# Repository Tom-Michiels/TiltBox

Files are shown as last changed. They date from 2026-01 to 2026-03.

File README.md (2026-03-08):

# TiltBox

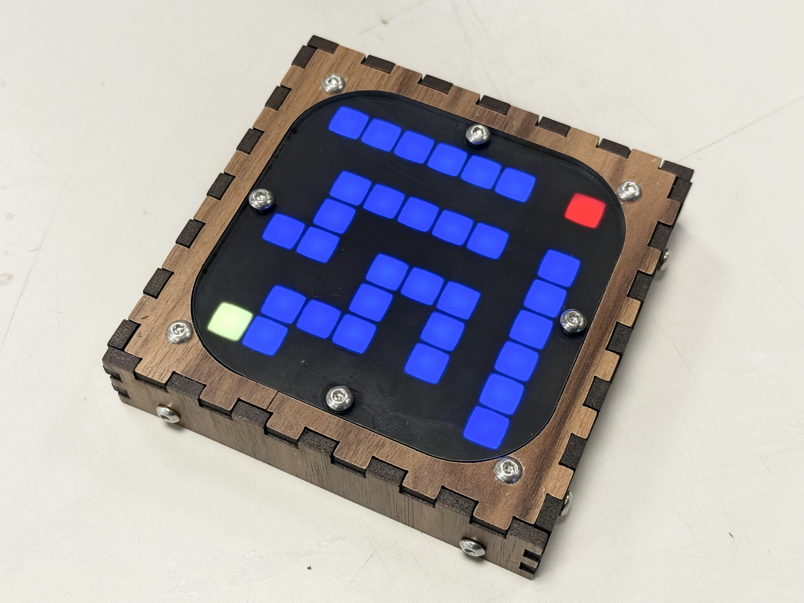
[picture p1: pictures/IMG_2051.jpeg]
TiltBox


A handheld retro game console with tilt controls, featuring 9 games on an 8x8 LED matrix. Designed at [Maakleerplek](https://maakleerplek.be).

## Bill of Materials

| Component | Quantity | Description | Link |
|---|---|---|---|
| ESP32-C3 | 1 | Microcontroller (any ESP32-C3 dev board) | [Amazon](https://www.amazon.de/diymore-ESP32-C3-Development-Supports-Bluetooth/dp/B0DS23ML1L/ref=sr_1_1_sspa?th=1) |
| WS2812 8x8 LED Matrix | 1 | 64 RGB LEDs in 8x8 grid | [Amazon](https://www.amazon.de/CJMCU-8x8-Development-Compatible-Arduino-Raspberry/dp/B0DDPWTH83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) |
| ADXL345 | 1 | 3-axis accelerometer module (I2C) | [Amazon](https://www.amazon.de/APKLVSR-ADXL345-Digital-Accelerating-Transmission/dp/B0CRVL4S54/ref=sr_1_2_sspa) |
| USB Charger Board | 1 | LiPo charging module with protection | [Amazon](https://www.amazon.de/-/en/dp/B09C34TK4F?th=1) |
| LiPo Battery | 1 | 3.7V lithium polymer battery | [Amazon](https://www.amazon.de/-/en/Seamuing-Lithium-Protective-Insulation-Development/dp/B087LTZW61/ref=sr_1_12) |
| Threaded Inserts | 4 | M3x5x7 heat-set inserts for enclosure | [Amazon](https://www.amazon.de/Threaded-RX-M3x5-7-Lead-Free-Bushings-Insertion/dp/B08BCRZZS3/ref=sr_1_1_sspa) |
| M3 Screws | 4 | M3x6mm hex socket button head | [Amazon](https://www.amazon.de/dp/B07ZPTX8B2?ref=ppx_yo2ov_dt_b_fed_asin_title) |
| M3 Screws | 4 | M3x12mm hex socket button head | [Amazon](https://www.amazon.de/dp/B07ZPT7Y9R?ref=ppx_yo2ov_dt_b_fed_asin_title&th=1) |
| Walnut Wood | 1 | 3.2mm x 115x368mm sheet | [Gravierbedarf](https://www.gravierbedarf.de/epages/63201300.sf/en_GB/?ObjectPath=/Shops/63201300/Products/NUSS) |
| Black PLA | 1 | 3D printer filament for enclosure | |
| Jumper wires | 7 | For connections | |

## Wiring

### WS2812 LED Matrix

| WS2812 Pin | ESP32-C3 Pin |
|---|---|
| VCC | 5V |
| GND | GND |
| DIN | GPIO 10 |

### ADXL345 Accelerometer (I2C)

| ADXL345 Pin | ESP32-C3 Pin |
|---|---|
| VCC | 3.3V |
| GND | GND |
| SDA | GPIO 8 |
| SCL | GPIO 9 |

## Build Instructions

### 1. 3D Printing

Print the enclosure parts in black PLA:

- [tilt_box.stl](hardware/tilt_box.stl) - Main enclosure body
- [tilt box grid.stl](hardware/tilt%20box%20grid.stl) - Grid overlay

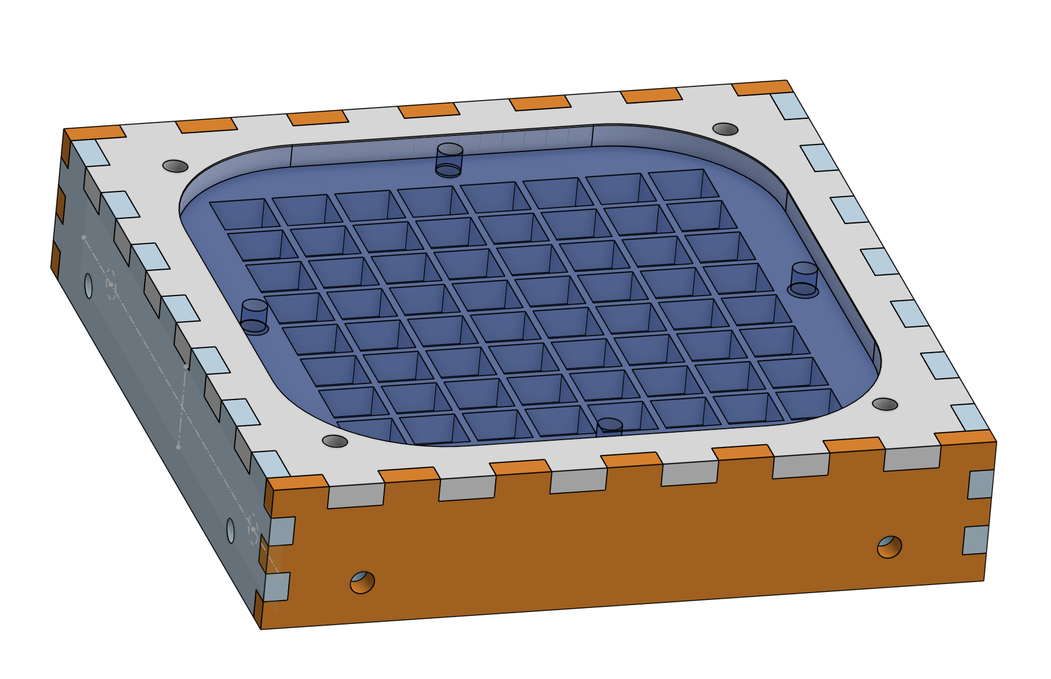
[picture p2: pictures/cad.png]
CAD Model


[Open in Onshape](https://cad.onshape.com/documents/1ea29db64e579952e6381490/w/44e133dfefb2de18973d13df/e/b5270f9dee790fa11f86224a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)

### 2. Laser Cutting

Cut the following from the [wood and plexi.dxf](hardware/wood%20and%20plexi.dxf) file:

- **Walnut wood** (3.2mm thickness): Front frame
- **Clear acrylic/plexi**: Screen cover

### 3. Soldering

Solder the components according to the wiring diagram:

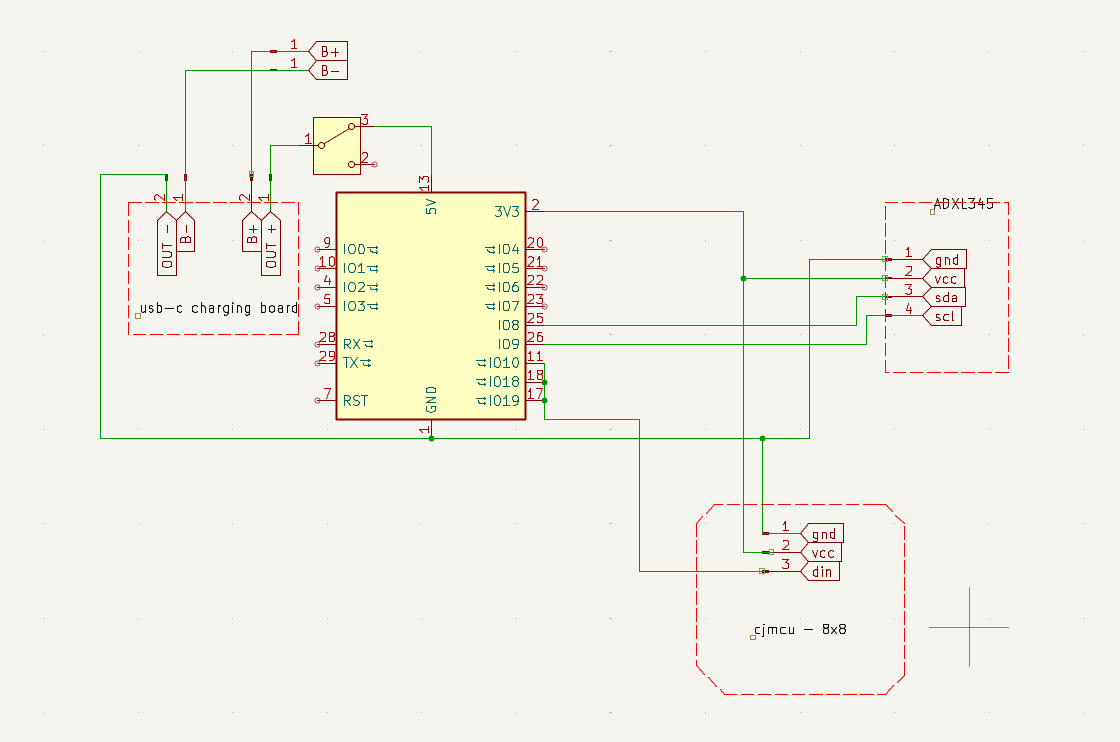
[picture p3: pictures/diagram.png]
Wiring Diagram


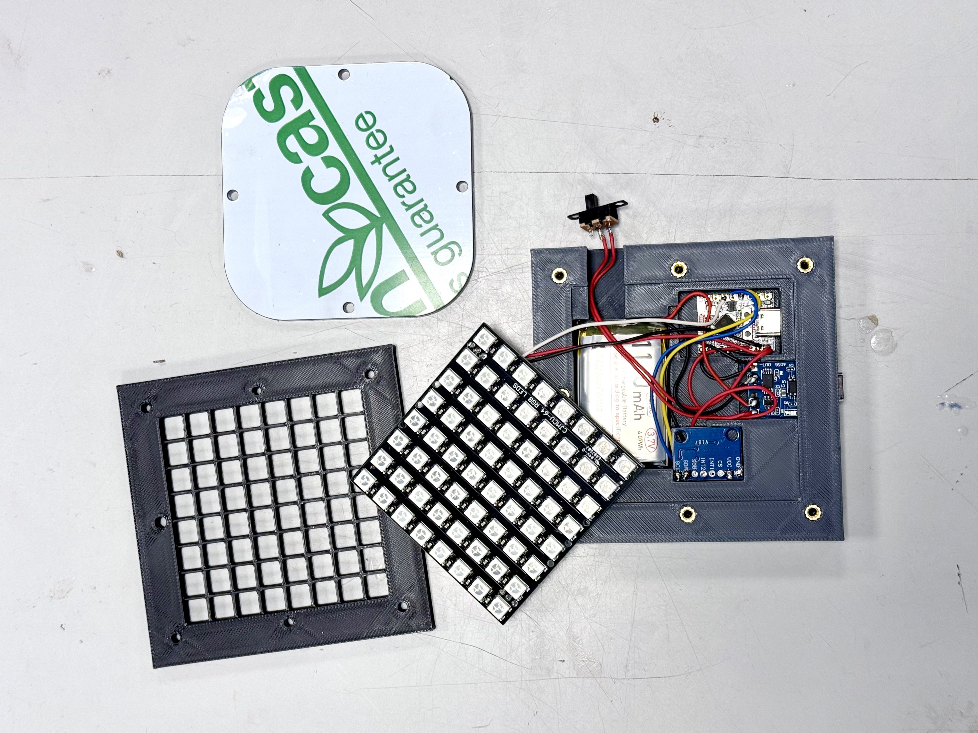
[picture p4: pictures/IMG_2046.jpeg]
Assembly


### 4. Screen Assembly

The LED matrix needs a diffuser layer to blend the individual LEDs into a smooth display:

- **Diffuser**: Use a white plastic bag or similar translucent material between the LED matrix and the plexi cover
- **Optional darkening**: Adding a dark PVC film (e.g. available at Lukas Creative) provides additional darkness to the screen, improving contrast

### 5. Final Assembly

1. Insert the M3x5x7 threaded inserts into the 3D printed enclosure using a soldering iron
2. Mount all electronics inside the enclosure
3. Stack the layers: LED matrix -> diffuser -> (optional dark film) -> plexi -> walnut frame
4. Secure with M3x6mm screws (front) and M3x12mm screws (back)

## Games

Switch between games by flipping the board upside down.

### 1. Maze
Navigate a ball through a randomly generated maze. Tilt to move the yellow ball to the red goal. A rainbow animation plays when you win.

### 2. Ball Trail
A simple ball that leaves a fading trail as it moves. Tilt to control direction.

### 3. Glow Ball
A glowing ball with a smooth gradient effect that follows your tilt movements.

### 4. Snake
Classic snake game. Tilt to change direction and eat the red food to grow. Don't hit yourself!

### 5. Breakout
Break the colored bricks at the top with a bouncing ball. Tilt left/right to move the paddle.

### 6. Dodge
Avoid falling obstacles. Tilt left/right to move your player at the bottom. Score increases as obstacles pass.

### 7. Scroll Text
Displays scrolling text: "maakleerplek"

### 8. Animation
Cycles through animated patterns:
- Spiral rainbow
- Wave
- Rainbow gradient

### 9. Tetris
Classic falling block game. Tilt left/right to move pieces, tilt forward to rotate, tilt backward for fast drop.

## Building and Flashing

Requires ESP-IDF v4.3+.

```bash
# Source ESP-IDF environment
source ~/esp/esp-idf/export.sh

# Build
idf.py build

# Flash
idf.py flash

# Monitor serial output
idf.py monitor
```

## Controls

- **Tilt**: Move/control in all games
- **Flip board**: Switch to next game
- **Keep level during startup**: Calibrates the accelerometer

## Display Format

The WS2812 LEDs use GRB color format. Pixels are addressed row by row, 0-63.

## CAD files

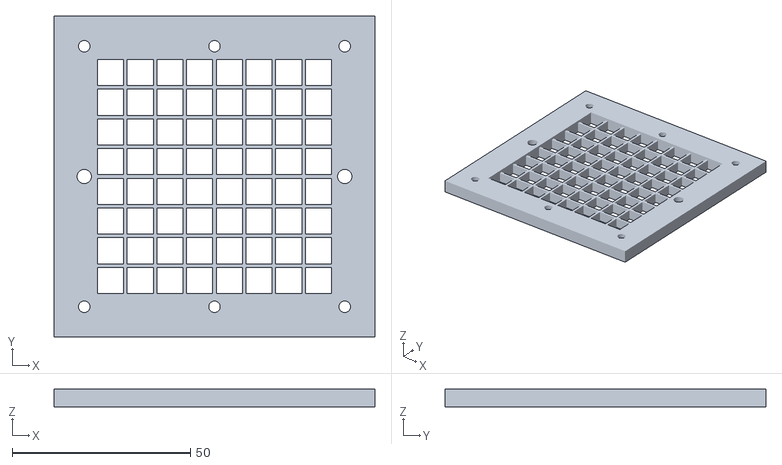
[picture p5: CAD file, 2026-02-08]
hardware/tilt box grid.stl
90.0 x 90.0 x 5.00

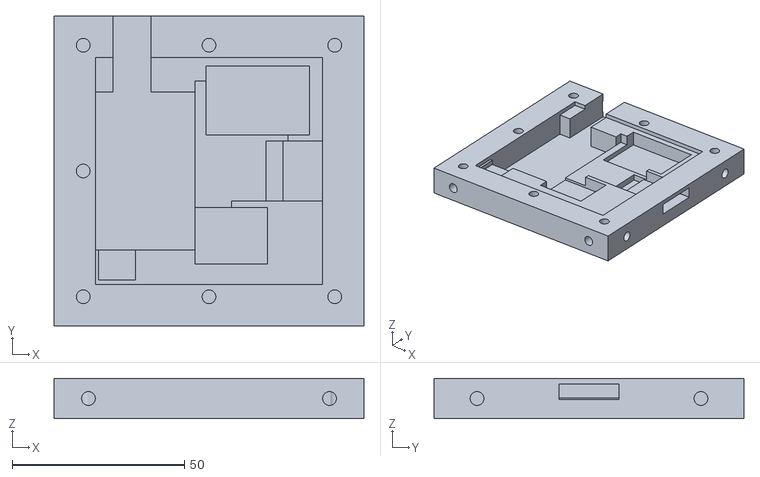
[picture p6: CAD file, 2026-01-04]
hardware/tilt_box.stl
90.0 x 90.0 x 11.7

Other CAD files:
hardware/wood and plexi.dxf

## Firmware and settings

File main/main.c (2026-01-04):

#include <stdio.h>
#include <string.h>
#include <math.h>
#include <stdlib.h>
#include "freertos/FreeRTOS.h"
#include "freertos/task.h"
#include "driver/rmt.h"
#include "driver/i2c.h"
#include "esp_system.h"

// I2C config
#define I2C_PORT        I2C_NUM_0
#define I2C_SDA         GPIO_NUM_8
#define I2C_SCL         GPIO_NUM_9
#define I2C_FREQ_HZ     100000

// ADXL345 registers
#define ADXL345_ADDR        0x53
#define ADXL345_DEVID       0x00
#define ADXL345_BW_RATE     0x2C
#define ADXL345_POWER_CTL   0x2D
#define ADXL345_DATA_FORMAT 0x31
#define ADXL345_DATAX0      0x32

// WS2812 config
#define WS2812_PIN      GPIO_NUM_10
#define RMT_CHANNEL     RMT_CHANNEL_0
#define LED_COUNT       64

// WS2812 timing (in RMT ticks at 10MHz = 100ns per tick)
#define T0H  4
#define T0L  8
#define T1H  8
#define T1L  4

// Colors (GRB format)
#define BLACK  0x00, 0x00, 0x00
#define WHITE  0xFF, 0xFF, 0xFF
#define RED    0x00, 0x40, 0x00
#define GREEN  0x40, 0x00, 0x00
#define BLUE   0x00, 0x00, 0x40
#define YELLOW 0x40, 0x40, 0x00

// Tilt threshold
#define TILT_THRESHOLD 25

// Flip detection
#define Z_POSITIVE_THRESHOLD  50
#define Z_NEGATIVE_THRESHOLD -50
#define FLIP_DEBOUNCE_COUNT   5

// Game types
typedef enum {
    GAME_MAZE,
    GAME_BALL_TRAIL,
    GAME_GLOW_BALL,
    GAME_SNAKE,
    GAME_BREAKOUT,
    GAME_DODGE,
    GAME_SCROLL_TEXT,
    GAME_ANIMATION,
    GAME_TETRIS,
    GAME_COUNT
} game_t;

typedef struct {
    void (*init)(void);
    void (*update)(int16_t dx, int16_t dy, int16_t z);
    void (*draw)(void);
} game_interface_t;

typedef struct {
    int8_t x, y;
} position_t;

// Display buffers
static uint8_t led_data[LED_COUNT * 3];
static rmt_item32_t rmt_items[LED_COUNT * 24];

// Calibration values
static int16_t cal_x = 0, cal_y = 0;

// Current game state
static game_t current_game = GAME_MAZE;

// Flip detection state
static bool z_positive = true;
static int flip_debounce_counter = 0;

// Animation frame counter (shared)
static uint32_t anim_frame = 0;

// ============ Ball with Trail Game ============
#define TRAIL_LENGTH 8
static position_t trail_buffer[TRAIL_LENGTH];
static int trail_head = 0;
static int ball_x = 3;
static int ball_y = 3;

// ============ Glow Ball Game ============
static float glow_ball_x = 3.5f;
static float glow_ball_y = 3.5f;

// ============ Snake Game ============
#define MAX_SNAKE_LENGTH 64
#define SNAKE_MOVE_INTERVAL 6
static position_t snake_body[MAX_SNAKE_LENGTH];
static int snake_length = 3;
static int8_t snake_dir_x = 1, snake_dir_y = 0;
static position_t food_pos;
static bool snake_alive = true;
static int snake_move_counter = 0;

// ============ Maze Game ============
static uint8_t maze[8];
static position_t maze_ball;
static position_t maze_goal;
static bool maze_won = false;
static int maze_win_counter = 0;

// ============ Dodge Game ============
static int dodge_player_x = 3;
static int16_t dodge_last_dx = 0;  // For hysteresis
static float dodge_obstacles[8];  // Y position of obstacle in each column (-1 = none)
static int dodge_score = 0;
static bool dodge_alive = true;
static int dodge_anim_counter = 0;
static int dodge_speed_counter = 0;
static float dodge_fall_speed = 0.15f;

// ============ Scroll Text Game ============
static float scroll_pos = 8.0f;  // Start off-screen to the right

// ============ Breakout Game ============
static int breakout_paddle_x = 3;        // Paddle center position (0-7)
static int16_t breakout_last_dx = 0;     // For hysteresis
static float breakout_ball_x = 3.5f;     // Ball position (float for smooth movement)
static float breakout_ball_y = 5.5f;
static float breakout_ball_vx = 0.3f;    // Ball velocity
static float breakout_ball_vy = -0.3f;
static uint8_t breakout_bricks[3];       // 3 rows of 8 bricks (bitmask)
static int breakout_bricks_left = 24;
static bool breakout_won = false;
static bool breakout_lost = false;
static int breakout_anim_counter = 0;

// ============ Animation Mode ============
typedef enum {
    ANIM_SPIRAL,
    ANIM_WAVE,
    ANIM_RAINBOW,
    ANIM_COUNT
} animation_t;
static animation_t current_anim = ANIM_SPIRAL;
static uint32_t anim_cycle_counter = 0;
#define ANIM_CYCLE_FRAMES 200

// ============ Tetris Game ============
#define TETRIS_DROP_INTERVAL 12
#define TETRIS_MOVE_DELAY 3
static uint8_t tetris_board[8];  // 8 rows, each byte is 8 columns (bitmask)
static int8_t tetris_piece_x, tetris_piece_y;  // Current piece position
static int8_t tetris_piece_type;  // 0-6 for I,O,T,S,Z,L,J
static int8_t tetris_piece_rot;   // 0-3 rotation
static int tetris_drop_counter;
static int tetris_move_counter;
static bool tetris_game_over;
static int tetris_anim_counter;
static int16_t tetris_last_dx;

// Tetromino shapes: 4 rotations each, stored as 4x4 bitmask (16 bits)
// Encoded as which cells are filled relative to piece origin
static const uint16_t tetris_pieces[7][4] = {
    // I piece
    {0x0F00, 0x2222, 0x00F0, 0x4444},
    // O piece
    {0x6600, 0x6600, 0x6600, 0x6600},
    // T piece
    {0x0E40, 0x4C40, 0x4E00, 0x4640},
    // S piece
    {0x06C0, 0x8C40, 0x6C00, 0x4620},
    // Z piece
    {0x0C60, 0x4C80, 0xC600, 0x2640},
    // L piece
    {0x0E80, 0xC440, 0x2E00, 0x44C0},
    // J piece
    {0x0E20, 0x44C0, 0x8E00, 0xC440},
};

// Piece colors (GRB format)
static const uint8_t tetris_colors[7][3] = {
    {0x40, 0x00, 0x40},  // I - cyan
    {0x40, 0x40, 0x00},  // O - yellow
    {0x20, 0x00, 0x40},  // T - purple
    {0x40, 0x00, 0x00},  // S - green
    {0x00, 0x40, 0x00},  // Z - red
    {0x20, 0x40, 0x00},  // L - orange
    {0x00, 0x00, 0x40},  // J - blue
};

// Forward declarations
static void ball_trail_init(void);
static void ball_trail_update(int16_t dx, int16_t dy, int16_t z);
static void ball_trail_draw(void);

static void glow_ball_init(void);
static void glow_ball_update(int16_t dx, int16_t dy, int16_t z);
static void glow_ball_draw(void);

static void snake_init(void);
static void snake_update(int16_t dx, int16_t dy, int16_t z);
static void snake_draw(void);

static void maze_init(void);
static void maze_update(int16_t dx, int16_t dy, int16_t z);
static void maze_draw(void);

static void breakout_init(void);
static void breakout_update(int16_t dx, int16_t dy, int16_t z);
static void breakout_draw(void);

static void dodge_init(void);
static void dodge_update(int16_t dx, int16_t dy, int16_t z);
static void dodge_draw(void);

static void scroll_text_init(void);
static void scroll_text_update(int16_t dx, int16_t dy, int16_t z);
static void scroll_text_draw(void);

static void animation_init(void);
static void animation_update(int16_t dx, int16_t dy, int16_t z);
static void animation_draw(void);

static void tetris_init(void);
static void tetris_update(int16_t dx, int16_t dy, int16_t z);
static void tetris_draw(void);

// Game dispatch table
static const game_interface_t game_table[GAME_COUNT] = {
    { maze_init, maze_update, maze_draw },
    { ball_trail_init, ball_trail_update, ball_trail_draw },
    { glow_ball_init, glow_ball_update, glow_ball_draw },
    { snake_init, snake_update, snake_draw },
    { breakout_init, breakout_update, breakout_draw },
    { dodge_init, dodge_update, dodge_draw },
    { scroll_text_init, scroll_text_update, scroll_text_draw },
    { animation_init, animation_update, animation_draw },
    { tetris_init, tetris_update, tetris_draw },
};

// ============ Display Functions ============

static int get_led_index(int row, int col)
{
    return row * 8 + col;
}

static void set_pixel_at(int row, int col, uint8_t g, uint8_t r, uint8_t b)
{
    if (row >= 0 && row < 8 && col >= 0 && col < 8) {
        int index = get_led_index(row, col);
        led_data[index * 3 + 0] = g;
        led_data[index * 3 + 1] = r;
        led_data[index * 3 + 2] = b;
    }
}

static void clear_display(void)
{
    memset(led_data, 0, sizeof(led_data));
}

static void ws2812_init(void)
{
    rmt_config_t config = {
        .rmt_mode = RMT_MODE_TX,
        .channel = RMT_CHANNEL,
        .gpio_num = WS2812_PIN,
        .clk_div = 8,
        .mem_block_num = 4,
        .tx_config = {
            .loop_en = false,
            .carrier_en = false,
            .idle_output_en = true,
            .idle_level = RMT_IDLE_LEVEL_LOW,
        }
    };
    rmt_config(&config);
    rmt_driver_install(RMT_CHANNEL, 0, 0);
}

static void ws2812_send(void)
{
    int item_idx = 0;
    for (int i = 0; i < LED_COUNT * 3; i++) {
        uint8_t byte = led_data[i];
        for (int bit = 7; bit >= 0; bit--) {
            if (byte & (1 << bit)) {
                rmt_items[item_idx].duration0 = T1H;
                rmt_items[item_idx].level0 = 1;
                rmt_items[item_idx].duration1 = T1L;
                rmt_items[item_idx].level1 = 0;
            } else {
                rmt_items[item_idx].duration0 = T0H;
                rmt_items[item_idx].level0 = 1;
                rmt_items[item_idx].duration1 = T0L;
                rmt_items[item_idx].level1 = 0;
            }
            item_idx++;
        }
    }
    rmt_write_items(RMT_CHANNEL, rmt_items, item_idx, true);
}

// ============ I2C / Accelerometer Functions ============

static void i2c_init(void)
{
    i2c_config_t conf = {
        .mode = I2C_MODE_MASTER,
        .sda_io_num = I2C_SDA,
        .scl_io_num = I2C_SCL,
        .sda_pullup_en = GPIO_PULLUP_ENABLE,
        .scl_pullup_en = GPIO_PULLUP_ENABLE,
        .master.clk_speed = I2C_FREQ_HZ,
    };
    i2c_param_config(I2C_PORT, &conf);
    i2c_driver_install(I2C_PORT, conf.mode, 0, 0, 0);
}

static esp_err_t adxl345_write_reg(uint8_t reg, uint8_t value)
{
    i2c_cmd_handle_t cmd = i2c_cmd_link_create();
    i2c_master_start(cmd);
    i2c_master_write_byte(cmd, (ADXL345_ADDR << 1) | I2C_MASTER_WRITE, true);
    i2c_master_write_byte(cmd, reg, true);
    i2c_master_write_byte(cmd, value, true);
    i2c_master_stop(cmd);
    esp_err_t ret = i2c_master_cmd_begin(I2C_PORT, cmd, pdMS_TO_TICKS(100));
    i2c_cmd_link_delete(cmd);
    return ret;
}

static esp_err_t adxl345_read_reg(uint8_t reg, uint8_t *data, size_t len)
{
    i2c_cmd_handle_t cmd = i2c_cmd_link_create();
    i2c_master_start(cmd);
    i2c_master_write_byte(cmd, (ADXL345_ADDR << 1) | I2C_MASTER_WRITE, true);
    i2c_master_write_byte(cmd, reg, true);
    i2c_master_start(cmd);
    i2c_master_write_byte(cmd, (ADXL345_ADDR << 1) | I2C_MASTER_READ, true);
    if (len > 1) {
        i2c_master_read(cmd, data, len - 1, I2C_MASTER_ACK);
    }
    i2c_master_read_byte(cmd, data + len - 1, I2C_MASTER_NACK);
    i2c_master_stop(cmd);
    esp_err_t ret = i2c_master_cmd_begin(I2C_PORT, cmd, pdMS_TO_TICKS(100));
    i2c_cmd_link_delete(cmd);
    return ret;
}

static esp_err_t adxl345_init(void)
{
    uint8_t devid;
    esp_err_t ret = adxl345_read_reg(ADXL345_DEVID, &devid, 1);
    if (ret != ESP_OK) return ret;
    if (devid != 0xE5) {
        printf("ADXL345 wrong ID: 0x%02X (expected 0xE5)\n", devid);
        return ESP_ERR_NOT_FOUND;
    }

    ret = adxl345_write_reg(ADXL345_BW_RATE, 0x0A);
    if (ret != ESP_OK) return ret;

    ret = adxl345_write_reg(ADXL345_DATA_FORMAT, 0x09);
    if (ret != ESP_OK) return ret;

    ret = adxl345_write_reg(ADXL345_POWER_CTL, 0x08);
    if (ret != ESP_OK) return ret;

    vTaskDelay(pdMS_TO_TICKS(10));
    return ESP_OK;
}

static esp_err_t adxl345_read(int16_t *x, int16_t *y, int16_t *z)
{
    uint8_t data[6];
    esp_err_t ret = adxl345_read_reg(ADXL345_DATAX0, data, 6);
    if (ret != ESP_OK) return ret;

    *x = (int16_t)((data[1] << 8) | data[0]);
    *y = (int16_t)((data[3] << 8) | data[2]);
    *z = (int16_t)((data[5] << 8) | data[4]);
    return ESP_OK;
}

static void calibrate_accel(void)
{
    int32_t sum_x = 0, sum_y = 0;
    int samples = 20;

    printf("Calibrating accelerometer - keep board level...\n");

    for (int i = 0; i < samples; i++) {
        int16_t x, y, z;
        if (adxl345_read(&x, &y, &z) == ESP_OK) {
            sum_x += x;
            sum_y += y;
        }
        vTaskDelay(pdMS_TO_TICKS(50));
    }

    cal_x = sum_x / samples;
    cal_y = sum_y / samples;

    printf("Calibration done: x=%d, y=%d\n", cal_x, cal_y);
}

// ============ Flip Detection ============

static bool check_game_switch(int16_t z)
{
    bool currently_positive = z > Z_POSITIVE_THRESHOLD;
    bool currently_negative = z < Z_NEGATIVE_THRESHOLD;

    if (z_positive && currently_negative) {
        flip_debounce_counter++;
        if (flip_debounce_counter >= FLIP_DEBOUNCE_COUNT) {
            z_positive = false;
            flip_debounce_counter = 0;
            return true;
        }
    } else if (!z_positive && currently_positive) {
        flip_debounce_counter++;
        if (flip_debounce_counter >= FLIP_DEBOUNCE_COUNT) {
            z_positive = true;
            flip_debounce_counter = 0;
        }
    } else {
        flip_debounce_counter = 0;
    }

    return false;
}

// ============ Utility Functions ============

static void hsv_to_rgb(uint8_t h, uint8_t s, uint8_t v, uint8_t *g, uint8_t *r, uint8_t *b)
{
    uint8_t region = h / 43;
    uint8_t remainder = (h - (region * 43)) * 6;
    uint8_t p = (v * (255 - s)) >> 8;
    uint8_t q = (v * (255 - ((s * remainder) >> 8))) >> 8;
    uint8_t t = (v * (255 - ((s * (255 - remainder)) >> 8))) >> 8;

    switch (region) {
        case 0:  *r = v; *g = t; *b = p; break;
        case 1:  *r = q; *g = v; *b = p; break;
        case 2:  *r = p; *g = v; *b = t; break;
        case 3:  *r = p; *g = q; *b = v; break;
        case 4:  *r = t; *g = p; *b = v; break;
        default: *r = v; *g = p; *b = q; break;
    }
}

// ============ Ball with Trail Game ============

static void ball_trail_init(void)
{
    ball_x = 3;
    ball_y = 3;
    trail_head = 0;
    for (int i = 0; i < TRAIL_LENGTH; i++) {
        trail_buffer[i].x = ball_x;
        trail_buffer[i].y = ball_y;
    }
}

static void ball_trail_update(int16_t dx, int16_t dy, int16_t z)
{
    (void)z;

    // Store current position in trail before moving
    trail_buffer[trail_head].x = ball_x;
    trail_buffer[trail_head].y = ball_y;
    trail_head = (trail_head + 1) % TRAIL_LENGTH;

    // Move ball - allow diagonal movement (X and Y independent)
    if (dx > TILT_THRESHOLD && ball_x < 7) ball_x++;
    if (dx < -TILT_THRESHOLD && ball_x > 0) ball_x--;

    if (dy > TILT_THRESHOLD && ball_y < 7) ball_y++;
    if (dy < -TILT_THRESHOLD && ball_y > 0) ball_y--;
}

static void ball_trail_draw(void)
{
    clear_display();

    // Draw trail (oldest to newest with increasing brightness)
    static const uint8_t brightness[] = {8, 15, 30, 50, 80, 120, 180, 255};
    for (int i = 0; i < TRAIL_LENGTH; i++) {
        int idx = (trail_head + i) % TRAIL_LENGTH;
        uint8_t b = brightness[i];
        set_pixel_at(trail_buffer[idx].y, trail_buffer[idx].x, b, b, b);
    }

    // Draw current ball (cyan/white)
    set_pixel_at(ball_y, ball_x, 0xFF, 0xFF, 0xFF);
}

// ============ Glow Ball Game ============

static void glow_ball_init(void)
{
    glow_ball_x = 3.5f;
    glow_ball_y = 3.5f;
}

static void glow_ball_update(int16_t dx, int16_t dy, int16_t z)
{
    (void)z;

    // Smooth movement based on tilt
    float move_x = dx / 150.0f;
    float move_y = dy / 150.0f;

    glow_ball_x += move_x;
    glow_ball_y += move_y;

    // Clamp to display bounds
    if (glow_ball_x < 0.0f) glow_ball_x = 0.0f;
    if (glow_ball_x > 7.0f) glow_ball_x = 7.0f;
    if (glow_ball_y < 0.0f) glow_ball_y = 0.0f;
    if (glow_ball_y > 7.0f) glow_ball_y = 7.0f;
}

static void glow_ball_draw(void)
{
    clear_display();

    // Draw gradient glow around ball
    for (int y = 0; y < 8; y++) {
        for (int x = 0; x < 8; x++) {
            // Calculate distance from ball (using float position)
            float dx = x - glow_ball_x;
            float dy = y - glow_ball_y;
            float dist = sqrtf(dx * dx + dy * dy);

            if (dist < 0.5f) {
                // Ball center - bright yellow
                set_pixel_at(y, x, 0x50, 0x50, 0x00);
            } else if (dist < 5.0f) {
                // Gradient glow - red/orange fading outward
                float intensity = (5.0f - dist) / 5.0f;
                intensity = intensity * intensity;  // Quadratic falloff for nicer glow

                uint8_t r = (uint8_t)(80.0f * intensity);
                uint8_t g = (uint8_t)(30.0f * intensity);
                uint8_t b = (uint8_t)(5.0f * intensity);

                // Add slight color shift based on position for more interest
                uint8_t hue_shift = ((x + y + (int)(anim_frame / 4)) * 8) & 0x1F;
                b += hue_shift / 2;

                set_pixel_at(y, x, g, r, b);
            }
        }
    }
}

// ============ Snake Game ============

static void spawn_food(void)
{
    bool valid;
    do {
        valid = true;
        food_pos.x = esp_random() % 8;
        food_pos.y = esp_random() % 8;
        // Check not on snake
        for (int i = 0; i < snake_length; i++) {
            if (snake_body[i].x == food_pos.x && snake_body[i].y == food_pos.y) {
                valid = false;
                break;
            }
        }
    } while (!valid);
}

static void snake_init(void)
{
    snake_length = 3;
    snake_alive = true;
    snake_dir_x = 1;
    snake_dir_y = 0;
    snake_move_counter = 0;

    // Initialize snake in center going right
    for (int i = 0; i < snake_length; i++) {
        snake_body[i].x = 3 - i;
        snake_body[i].y = 3;
    }

    spawn_food();
}

static void snake_update(int16_t dx, int16_t dy, int16_t z)
{
    (void)z;

    if (!snake_alive) {
        if (++snake_move_counter > 40) {
            snake_init();
        }
        return;
    }

    // Update direction from tilt (prevent 180 turns)
    if (abs(dx) > abs(dy)) {
        if (dx > TILT_THRESHOLD && snake_dir_x != -1) {
            snake_dir_x = 1; snake_dir_y = 0;
        } else if (dx < -TILT_THRESHOLD && snake_dir_x != 1) {
            snake_dir_x = -1; snake_dir_y = 0;
        }
    } else {
        if (dy > TILT_THRESHOLD && snake_dir_y != -1) {
            snake_dir_x = 0; snake_dir_y = 1;
        } else if (dy < -TILT_THRESHOLD && snake_dir_y != 1) {
            snake_dir_x = 0; snake_dir_y = -1;
        }
    }

    // Move snake at interval
    if (++snake_move_counter >= SNAKE_MOVE_INTERVAL) {
        snake_move_counter = 0;

        int8_t new_x = snake_body[0].x + snake_dir_x;
        int8_t new_y = snake_body[0].y + snake_dir_y;

        // Clamp to walls (don't die, just stop)
        if (new_x < 0) new_x = 0;
        if (new_x > 7) new_x = 7;
        if (new_y < 0) new_y = 0;
        if (new_y > 7) new_y = 7;

        // If we can't move (hit wall), just wait
        if (new_x == snake_body[0].x && new_y == snake_body[0].y) {
            return;
        }

        // Check self collision (still dies on self-hit, skip head at i=0)
        for (int i = 1; i < snake_length; i++) {
            if (snake_body[i].x == new_x && snake_body[i].y == new_y) {
                snake_alive = false;
                return;
            }
        }

        // Check food
        bool ate_food = (new_x == food_pos.x && new_y == food_pos.y);

        // Move body
        if (!ate_food) {
            for (int i = snake_length - 1; i > 0; i--) {
                snake_body[i] = snake_body[i-1];
            }
        } else {
            // Grow
            for (int i = snake_length; i > 0; i--) {
                snake_body[i] = snake_body[i-1];
            }
            if (snake_length < MAX_SNAKE_LENGTH) {
                snake_length++;
            }
            spawn_food();
        }

        snake_body[0].x = new_x;
        snake_body[0].y = new_y;
    }
}
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
void app_main(void)
{
    printf("Multi-Game LED Matrix starting...\n");

    ws2812_init();
    i2c_init();

    // Show green while initializing
    clear_display();
    set_pixel_at(3, 3, GREEN);
    ws2812_send();

    esp_err_t ret = adxl345_init();
    if (ret != ESP_OK) {
        printf("ADXL345 init failed: %d\n", ret);
        clear_display();
        set_pixel_at(3, 3, RED);
        ws2812_send();
        while (1) vTaskDelay(1000 / portTICK_PERIOD_MS);
    }

    printf("ADXL345 initialized\n");
    calibrate_accel();

    // Initialize flip detection state based on current orientation
    {
        int16_t x, y, z;
        if (adxl345_read(&x, &y, &z) == ESP_OK) {
            z_positive = (z > 0);
        }
    }

    // Initialize first game
    game_table[current_game].init();
    printf("Starting game %d\n", current_game);

    while (1) {
        int16_t x, y, z;

        if (adxl345_read(&x, &y, &z) == ESP_OK) {
            int16_t raw_dx = x - cal_x;
            int16_t raw_dy = y - cal_y;

            // Rotate 90 degrees counter-clockwise relative to sensor
            int16_t dx = -raw_dy;
            int16_t dy = raw_dx;

            // Check for game switch (flip detection)
            if (check_game_switch(z)) {
                current_game = (current_game + 1) % GAME_COUNT;
                game_table[current_game].init();
                printf("Switched to game %d\n", current_game);
            }

            // Update current game
            game_table[current_game].update(dx, dy, z);
        }

        // Increment shared animation frame
        anim_frame++;

        // Draw current game
        game_table[current_game].draw();
        ws2812_send();

        vTaskDelay(pdMS_TO_TICKS(50));
    }
}

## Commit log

2026-01-04 Add TiltBox project files
    - ESP32-C3 based LED matrix game console with tilt controls
    - 9 games: Maze, Ball Trail, Glow Ball, Snake, Breakout, Dodge, Scroll Text, Animation, Tetris
    - Hardware designs (STL, DXF) and documentation
    [tilt box grid.stl, tilt_box.stl, wood and plexi.dxf]
2026-02-08 fixed dxf
    [wood and plexi.dxf]
2026-02-08 Flip grid STL so print surface faces down
    [tilt box grid.stl]
2026-03-08 Add Onshape CAD link to README
